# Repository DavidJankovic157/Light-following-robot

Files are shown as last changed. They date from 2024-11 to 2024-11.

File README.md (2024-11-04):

A robot that moves away from light using the dsPIC30F4013 microcontroller and suitable sensors. The PCB for this project is designed with Altium Designer 17. Details on the sensors and code operation are provided in the documentation.

Upotrebom dsPIC30F4013 mikrokontrolera i odgovarajućih senzora realizovan je robot koji se kreće suprotno od izvora svetlosti. PCB za ovaj projekat realizovan je pomoću Altium Designer-a 17. Detaljne informacije o senzorima i principu rada koda nalaze se u pratećoj dokumentaciji.

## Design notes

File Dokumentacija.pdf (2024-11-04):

# PROJEKAT IZ PRIMENJENE ELEKTRONIKE

NAZIV PROJEKTA:

Autonomni robot za detekciju svetlosti i izbegavanje prepreka

MENTOR PROJEKTA:

Prof. dr Vladimir Rajs

Msc Milan Bodić

Msc Marko Vasiljević Toskić

PROJEKAT IZRADILI:

Anđela Smiljanić ee133/2019

Luka Urošević ee154/2019

David Janković ee157/2019

DATUM ODBRANE PROJEKTA:

## Sadržaj

## 1. Uvod

Kada smo bili deca igrali smo se sa raznim igračkama koje su se kretale po unapred zadatim putanjama, bez obzira na prepreke koje predstoje. Ovaj projekat podseća na te trenutke, ali sada umesto praćene fiksne rute, reaguje na promene u okruženju, prilagođava svoje kretanje prema svetlosti i izbegava prepreke.

Cilj ovog projekta je razviti algoritam koji omogućava robotu da se kreće u pravcu suprotnom od izvora svetlosti, koristeći fotootpornike za detekciju njenog intenziteta. Postavljanje četiri fotootpornika omogućava robotu da „oseća“ svetlost iz različitih pravaca i automatski prilagođava svoj pravac kretanja – povlači se iz osvetljenih zona i traži tamnija područja.

Robot takođe koristi Bluetooth komunikaciju za primanje jednostavnih komandi "START" i "STOP", pružajući korisniku mogućnost da započne ili prekine njegovo kretanje u bilo kom trenutku. Bluetooth modul nije samo sredstvo kontrole, već i veza koja robotu daje mogućnost interakcije sa spoljnim svetom, otvarajući vrata za dalji razvoj sistema koji mogu reagovati na složenije signale.

Da bi osigurao sigurno kretanje, robot je opremljen sa dva HC-SR04 senzora za izbegavanje prepreka, čime postaje sposoban da se autonomno kreće bez rizika od sudara. Ovi senzori skeniraju okolinu ispred i iza robota, omogućavajući mu da izbegne prepreke i sačuva stabilnost u svakoj fazi kretanja.

Na taj način, ovaj projekat predstavlja savršenu kombinaciju jednostavnih tehnologija, poput fotootpornika i senzora daljine, sa osnovnim elementima robotike i komunikacije. Rezultat je robot koji uči da reaguje na svetlo i prepreke, pružajući korisniku jedinstven uvid u svet interaktivnih i autonomnih sistema.

## 2. Opis elemenata projekta

2.1.Bluetooth HC- 06

HC-06 Bluetooth modul je jednostavan i pouzdan uređaj koji omogućava bežičnu komunikaciju sa pametnim telefonima, računarima ili drugim Bluetooth uređajima. Konfigurisan je kao slave uređaj, što znači da uvek čeka da se poveže sa uređajem koji je konfigurisani kao master, kao što su telefoni ili računari. Modul podržava Bluetooth verziju 2.0 i omogućava prenos podataka pri brzinama do 2.1 Mbps, što ga čini pogodnim za mnoge projekte koji zahtevaju pouzdanu bežičnu vezu.

HC-06 koristi radni napon od 3.3V i ima radnu struju manju od 40mA, što ga čini efikasnim u potrošnji energije. Komunikacija sa ovim modulom ostvaruje se putem UART interfejsa, što omogućava jednostavno povezivanje sa mikrokontrolerima i drugim uređajima koji podržavaju serijski port. Modul dolazi sa integrisanom antenom koja omogućava stabilan prenos podataka na udaljenosti do 10 metara, što je dovoljno za mnoge aplikacije gde se traži bežična kontrola ili prenos podataka.

Povezivanje HC-06 sa mikrokontrolerom je prilično jednostavno. Modul ima četiri pina – VCC, GND, TX i RX. VCC pin se povezuje
na napajanje od 3.3V, GND na uzemljenje,
dok se TX i RX koriste za slanje i primanje
podataka.

Kada se uključi, HC-06 postaje dostupan za uparivanje, a pametni telefon ili računar mogu ga pronaći putem Bluetooth
pretrage. Nakon što je uparen, uređaj može
slati i primati podatke preko serijskog

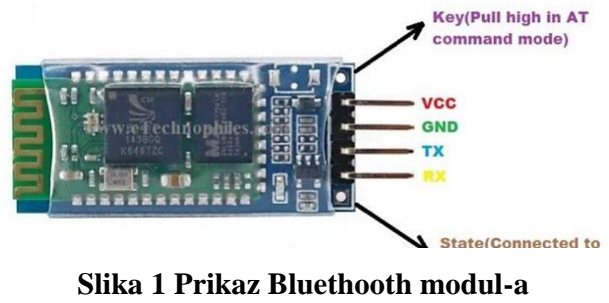
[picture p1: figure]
Slika 1 Prikaz Bluethooth modul-a

interfejsa. To omogućava jednostavnu implementaciju bežične kontrole robota, prikupljanje podataka sa senzora ili daljinsko upravljanje različitim uređajima.

HC-06 je široko korišćen u projektima koji zahtevaju bežičnu komunikaciju, posebno u robotici, Internet of Things (IoT) uređajima i aplikacijama gde je potrebna jednostavna bežična interakcija sa mikrokontrolerom. [1]

2.2.Ultrazvučni senzor HC-SR04

Ovaj projekat koristi HC-SR04 ultrazvučni senzor kako bi robot mogao da detektuje prepreke i meri udaljenost od objekata u svom okruženju. Cilj je da robot autonomno izbegava prepreke, koristeći podatke o udaljenosti u realnom vremenu, što omogućava glatko i bezbedno kretanje. Senzor funkcioniše tako što emituje ultrazvučni signal koji se odbija od objekata, a zatim meri vreme potrebno da se taj signal vrati. Na osnovu izmerenog vremena, izračunava se udaljenost do objekta. HC-SR04 može meriti udaljenost u rasponu od 2 cm do 4 metra, pružajući precizne i pouzdane informacije.

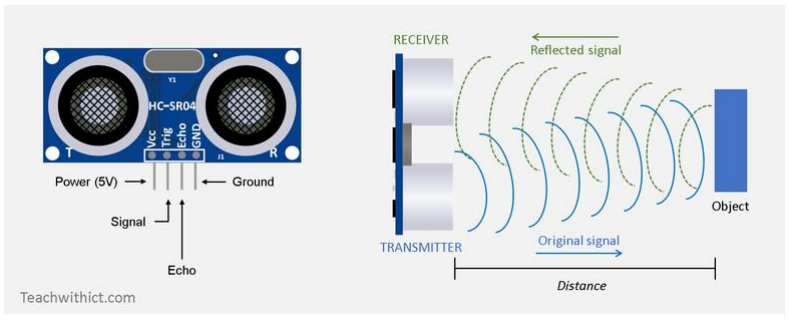
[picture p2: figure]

Komunikacija sa senzorom je jednostavna i ostvaruje se putem četiri pina – VCC, GND, Trigger i Echo. VCC pin se povezuje na napajanje od 3.3V ili 5V, dok se GND povezuje na uzemljenje. Trigger pin je zadužen za slanje impulsa mikrokontrolera, a Echo pin vraća signal koji predstavlja dužinu trajanja eha. Na osnovu ovog povratnog signala mikrokontroler izračunava vreme koje je bilo potrebno da se ultrazvučni talas odbije od prepreke i vrati, a zatim na osnovu toga računa udaljenost do objekta koristeći formulu:

D =

V ∗ T
2
Gde je D rastojanje, V brzina zvuka (340 m/s), a T proteklo vreme od emitovanja do povratka talasa. Proizvod brzine zvuka i proteklog vremena deli se sa dva jer talasi putuju od modula do prepreke i nazad.

Brzina zvuka je ključna za precizno merenje udaljenosti. Na primer, na temperaturi od 20℃ u suvom vazduhu, brzina zvuka je oko 340 m/s. Ovo daje dovoljno vremena da senzor pošalje impuls i primi povratni signal. Međutim, brzina prostiranja zvuka može značajno varirati u različitim sredinama – u tečnostima može biti preko 1000 m/s, a u čvrstim materijalima i nekoliko hiljada metara u sekundi. S obzirom na ove faktore, HC-SR04 je pouzdano rešenje za detekciju prepreka u vazduhu, omogućavajući robotima da izbegnu sudare u realnom vremenu.

Zahvaljujući jednostavnosti korišćenja, ovaj senzor je pogodan za različite aplikacije, od robotike i detekcije prepreka, do naprednijih sistema za merenje i navigaciju. [2]

Slika 2.2a Ultrazvučni senzor

2.3.Fotootpornik

Ovaj otpornik je izrađen od poluprovodnog materijala. Kada fotoni svetlosti padaju na fotootpornik sa dovoljno visokom frekvencijom (odnosno dovoljnom energijom), oni pružaju vezanim elektronima dovoljnu energiju da postanu slobodni elektroni u poluprovodniku. Ovaj proces rezultuje smanjenjem otpora fotootpornika pod uticajem svetlosti.

Fotootpornici imaju prednosti u vidu niske cene i pouzdanosti, ali imaju i svoje nedostatke, među kojima je spor odziv. Naime, obično je potrebno nekoliko sekundi za potpunu promenu otpora fotootpornika prilikom naglog promenjenog osvetljenja. Ovo često može biti ograničavajuće u situacijama gde je brza reakcija na promene u osvetljenju od suštinskog značaja. [3]

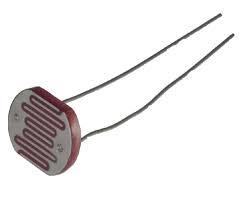
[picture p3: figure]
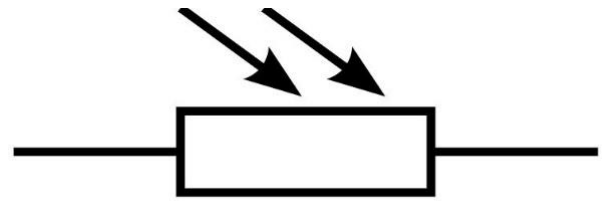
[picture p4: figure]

Slika 2a izgled fotootpornika(levo) i šematski prikaz(desno)

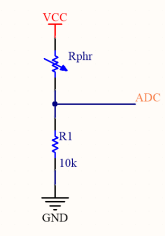
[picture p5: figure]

Slika 2b Izgled šematika za povezivanje fotootporinika sa mikrokontrolerom

2.4.Programator
PICkit je serija programatora za PIC mikrokontrolere koju proizvodi Microchip Technology. Ovi uređaji se koriste za programiranje mikrokontrolera, otklanjanje grešaka i programiranje EEPROM memorija. U našem projektu koristili smo PICkit 2, koji se izdvaja po tome što ima odvojenu jedinicu za programiranje i debagovanje koja se povezuje sa pločom na kojoj se nalazi čip koji treba programirati.

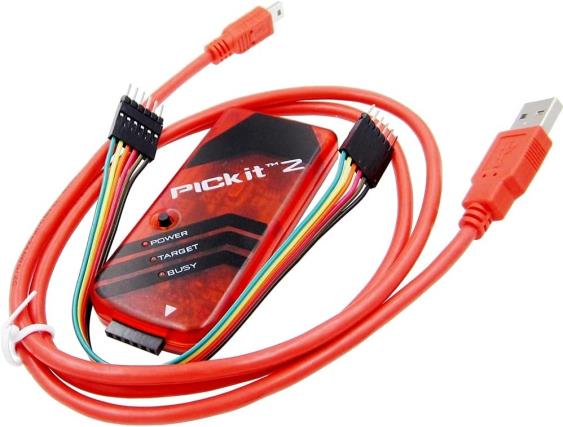
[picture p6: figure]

PICkit 2 dolazi sa 128 KB memorije kao standardnom opremom, dok je moguće proširiti kapacitet na 256 KB modifikovanjem hardvera ili korišćenjem klonova trećih strana. Ovaj programator takođe uključuje ugrađeni trokanalni logički analizator od 500 kHz i UART alat, što dodatno olakšava analizu i debagovanje sistema.

Sistem PICkit 2 sadrži pet ključnih pinova za programiranje mikrokontrolera: VDD (napajanje), VSS (masa), PGD (Program Data), PGC (Program Clock) i MCLR (RESET), uz dodatni šesti slobodni pin. Pinovi PGC i PGD su povezani sa RB6 i RB7 pinovima mikrokontrolera, omogućavajući efikasnu komunikaciju i programiranje. [4]

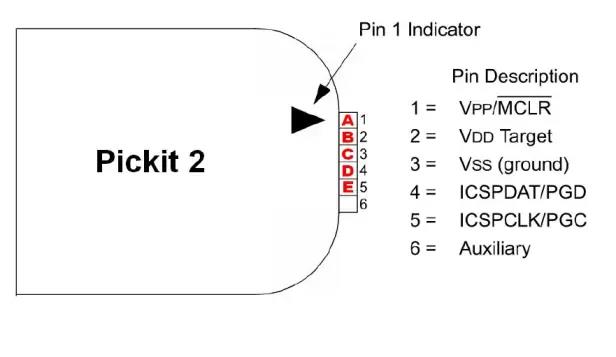
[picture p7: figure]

Slika 2.4b Pickit 2 pinovi

Slika 2.4a Pickit 2

## 3. HARDVERSKA STRUKTURA

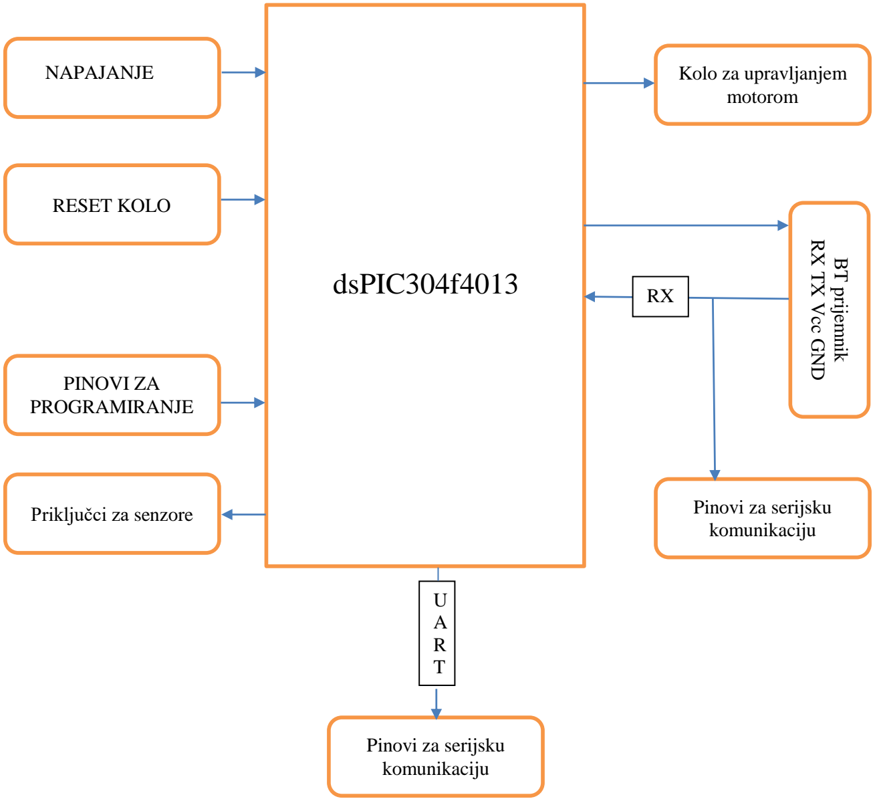
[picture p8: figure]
RESET KOLO; Priključci za senzore; PINOVI ZA PROGRAMIRANJE; Kolo za upravljanjem motorom; BT prijemnik; RX TX Vcc GND; Pinovi za serijsku komunikaciju; dsPIC304f4013; NAPAJANJE

## 4. ŠEMATIK

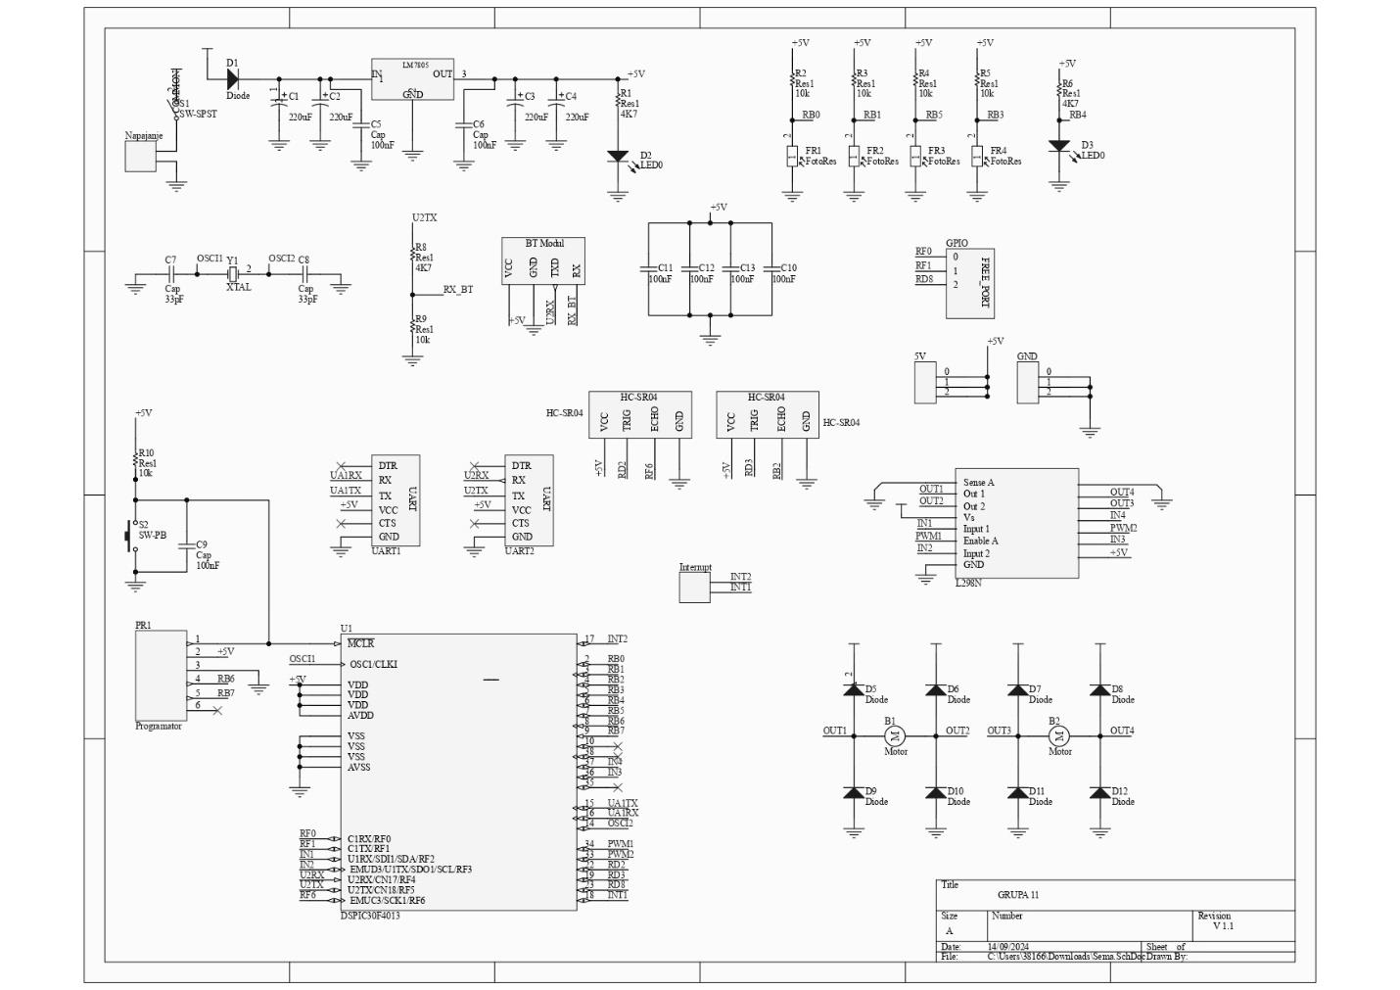
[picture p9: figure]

Slika 4.1a Izgled šematika u Altium Designer-u

## 5. OPIS PODSISTEMA ŠEMATIKA

### 5.1. Blok za napajanje

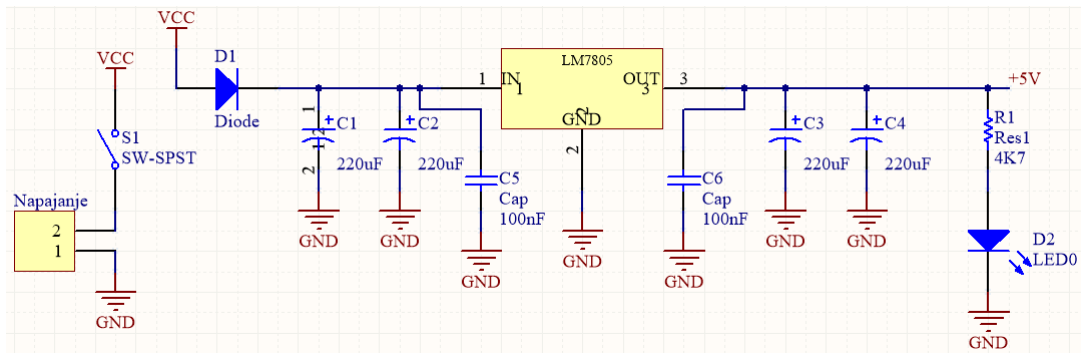
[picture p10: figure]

Slika 5.1a Šematski prikaz bloka za napajanje

Glavni deo ovog segmenta čini stabilizator napona LM7805.

On predstavlja jedan od najčešćih naponskih regulatora korišćen za ograničavanje napona. Na izlazu naponskog regulatora dobija se vrednost od 5V sa 2% maksimalne devijacije.

Kako bi se ostvario stabilan izlaz, neophodno je napajati kolo sa minimum 7V. Za potrebe projekta je upotrebljeno napajanje od 9V. Na izlazu kola nalazi se LED koja služi za indikaciju da li je kolo u funkciji. [5]

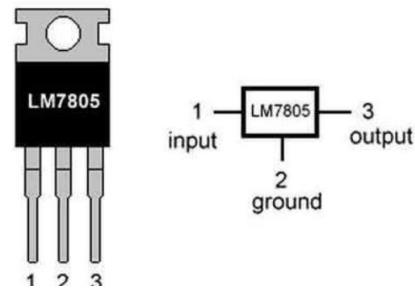
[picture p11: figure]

Slika 5.1b Izgled kućišta LM7805 sa rasporedom pinova

### 5.2. Mikrokontroler dsPIC30f4013

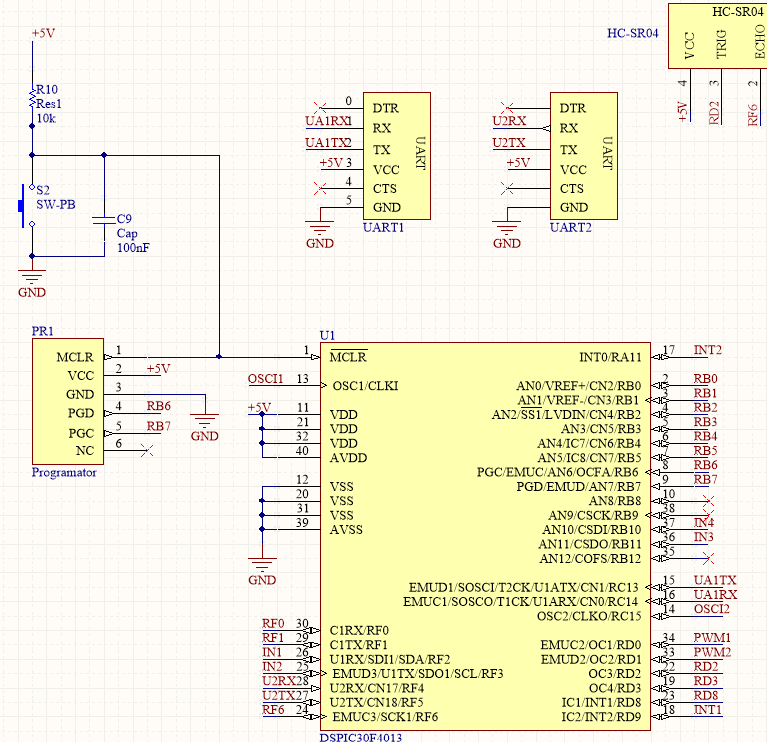
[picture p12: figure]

Slika 5.2a Šematski prikaz mikrokontrolera dsPIC30f4013

Mikrokontroleri su postali neophodni element svakog elektronskog uređaja, igrajući ključnu ulogu u prikupljanju podataka, ograničene obrade tih podataka i upravljanju okruženjem na osnovu rezultata izračunavanja. U okviru ovog projekta, izabran je mikrokontroler dsPIC30f4013 proizvođača Microchip. Ovaj mikrokontroler ima radni napon radni napon u rasponu od 2.5V do 5.5V. Poseduje pet vrsta portova (A,B,C,D,E,F), pet tajmera, dva UART modula sa FIFO baferima i 12-bitni Analogno-Digitalni (A/D) konvertor sa 13 ulaznih kanala. Njegove karakteristike uključuju nisku potrošnju energije i visoku brzinu rada. [6]

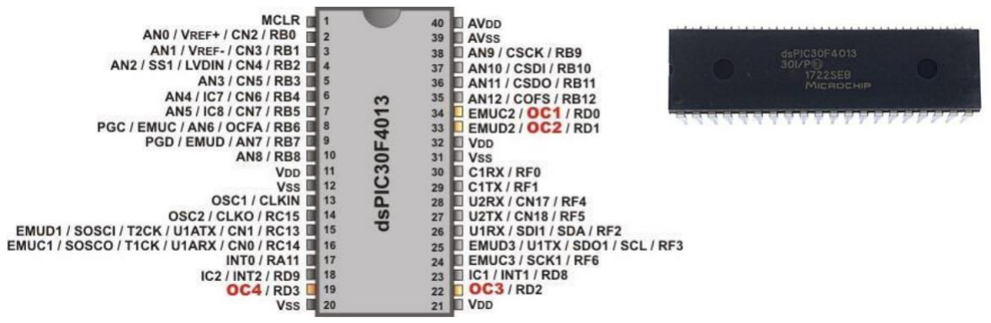
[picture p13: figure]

Slika 5.2b Raspored priključaka Mikrokontrolera dsPIC30f4013(levo) i izgled mikrokontrolera(desno)

U zadatku smo koristili eksterni oscilator čiji je instrukcioni takt iznosi 10MHz.

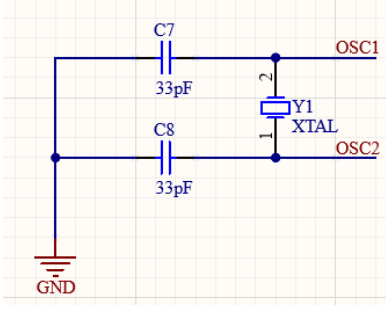
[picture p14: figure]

Slika 5.2c Prikaz oscilatora

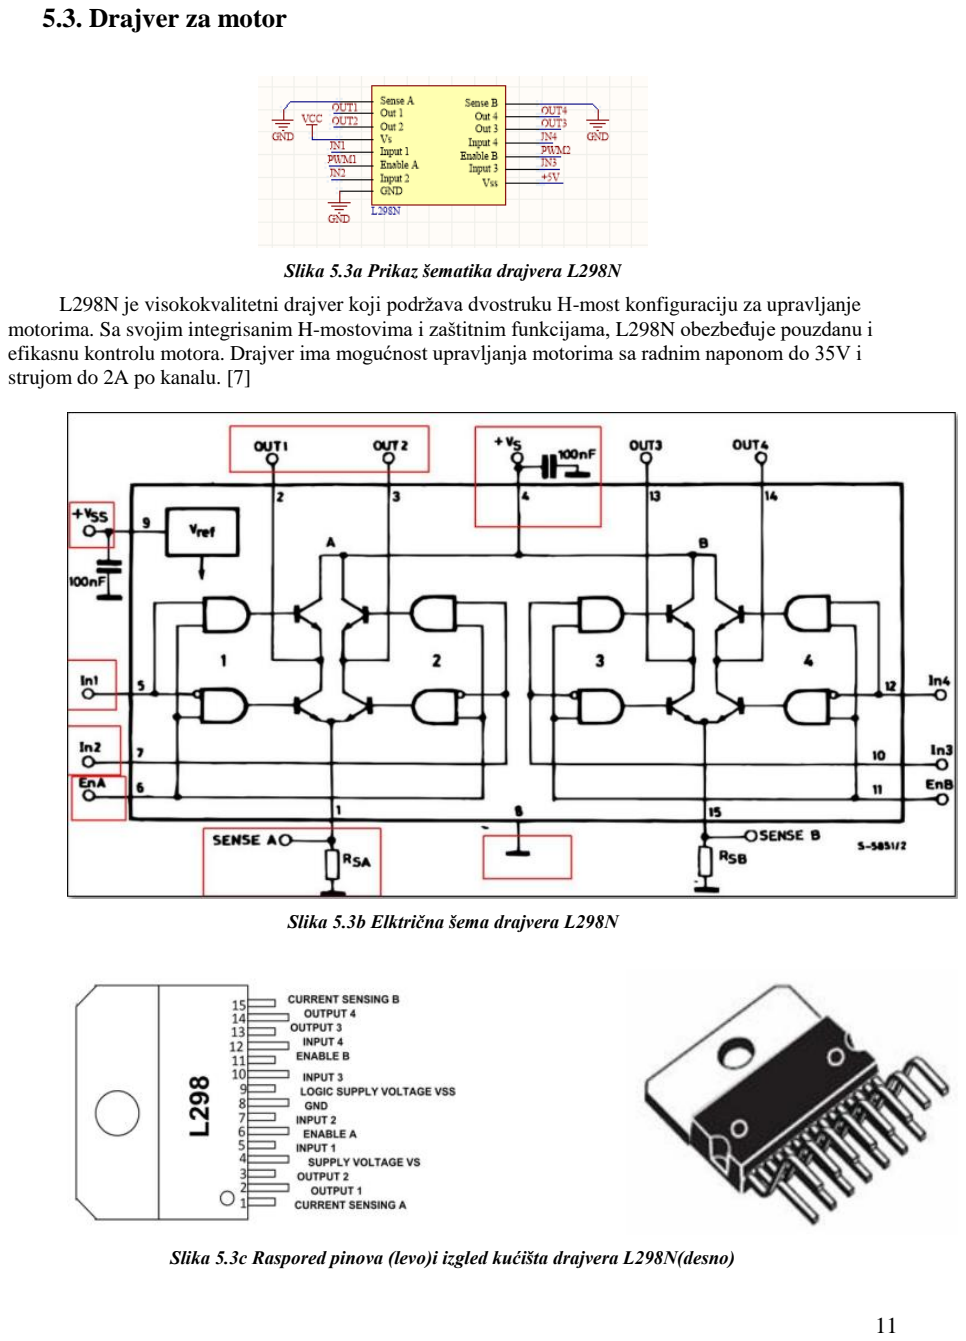
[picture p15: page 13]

### 5.3. Drajver za motor

Slika 5.3a Prikaz šematika drajvera L298N L298N je visokokvalitetni drajver koji podržava dvostruku H-most konfiguraciju za upravljanje motorima. Sa svojim integrisanim H-mostovima i zaštitnim funkcijama, L298N obezbeđuje pouzdanu i efikasnu kontrolu motora. Drajver ima mogućnost upravljanja motorima sa radnim naponom do 35V i strujom do 2A po kanalu. [7]

Slika 5.3b Elktrična šema drajvera L298N

Slika 5.3c Raspored pinova (levo)i izgled kućišta drajvera L298N(desno)

### 5.4. Reset kolo

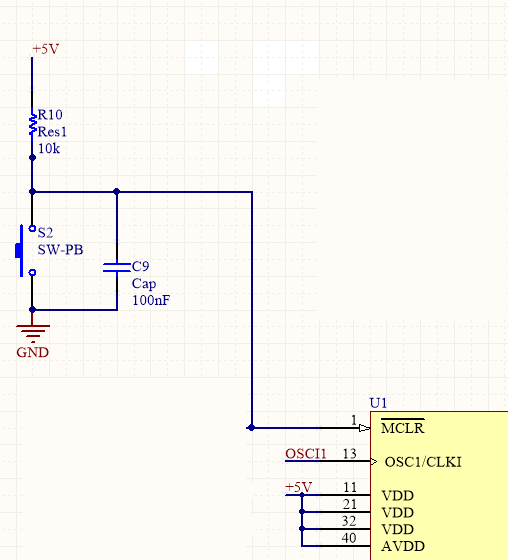
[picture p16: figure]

Slika 5.4a Šematik reset kola

Reset kolo služi da se resetuje mikrokontroler. Realizovano je u vidu pull-up tastera, kod koga se taster nalazi paralelno kondenzatoru (100pF), jedan kraj ide na masu, drugi na otpornik koji se povezuje na napajanje (5V). Kondenzator služi kao hardversko rešenje poskakivanju tastera (eng. debouncing). Izlaz reset kola je izmedju otpornika i paralelne veze tastera i kondenzatora. Pritiskom na taster dobijamo nizak logički nivo, što signalizira sistemu da izvrši reset i odgovara samom MCLR ̅̅̅̅̅̅̅̅̅̅̅̅̅̅̅̅̅̅̅̅̅̅̅̅̅̅̅̅̅̅̅̅̅̅̅̅̅̅̅̅̅̅̅̅̅̅̅̅̅̅̅̅̅̅̅̅̅̅̅̅̅̅̅̅
na koji se vezuje izlaz
našeg reset kola. Kada se taster otpusti prekida se putanja ka masi i imamo visok logički nivo i vraćamo se u stanje mirovanja, neakativno stanje reset kola.

## 6. Prikaz PCB

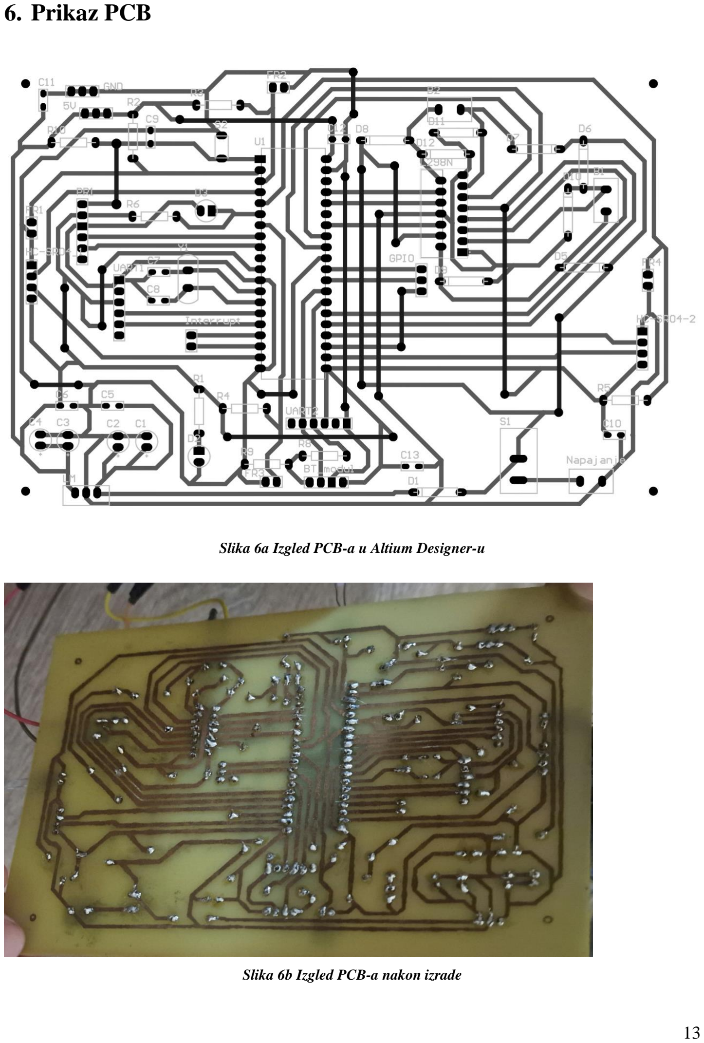
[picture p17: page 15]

Slika 6a Izgled PCB-a u Altium Designer-u

Slika 6b Izgled PCB-a nakon izrade

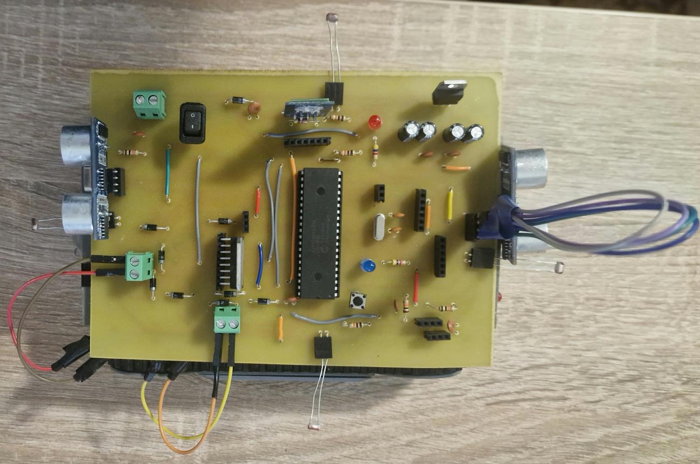
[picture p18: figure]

Slika 6c Izgled povezanog autića spreman za test

## 7. Izrada pločice

Koraci prilikom izrade štampane pločice:

- Priprema vitroplasta: Šmirglanje i čišćenje pločice.
- Prebacivanje dizajna: Prenos dizajna na pločicu peglanjem.
- Utapanje u kiselinu: Nagrizanje bakra na nepokrivenim delovima dizajna.
- Bušenje rupa: Izrada rupa za komponente.
- Postavljanje komponenata: Instalacija svih elektronskih delova.
- Testiranje: Provera funkcionalnosti pločice.

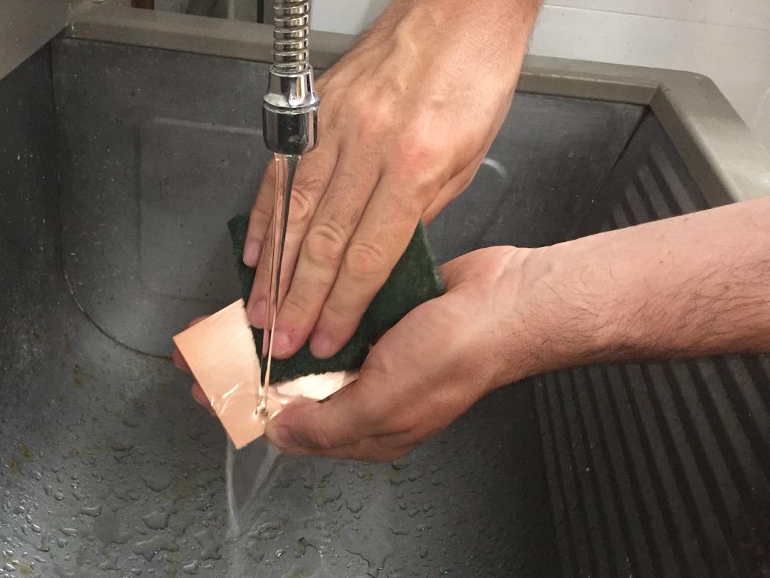
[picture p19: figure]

Slika 7a Način izrade PCB-a

## 8. Algoritam rada

8.1Prikaz algoritma

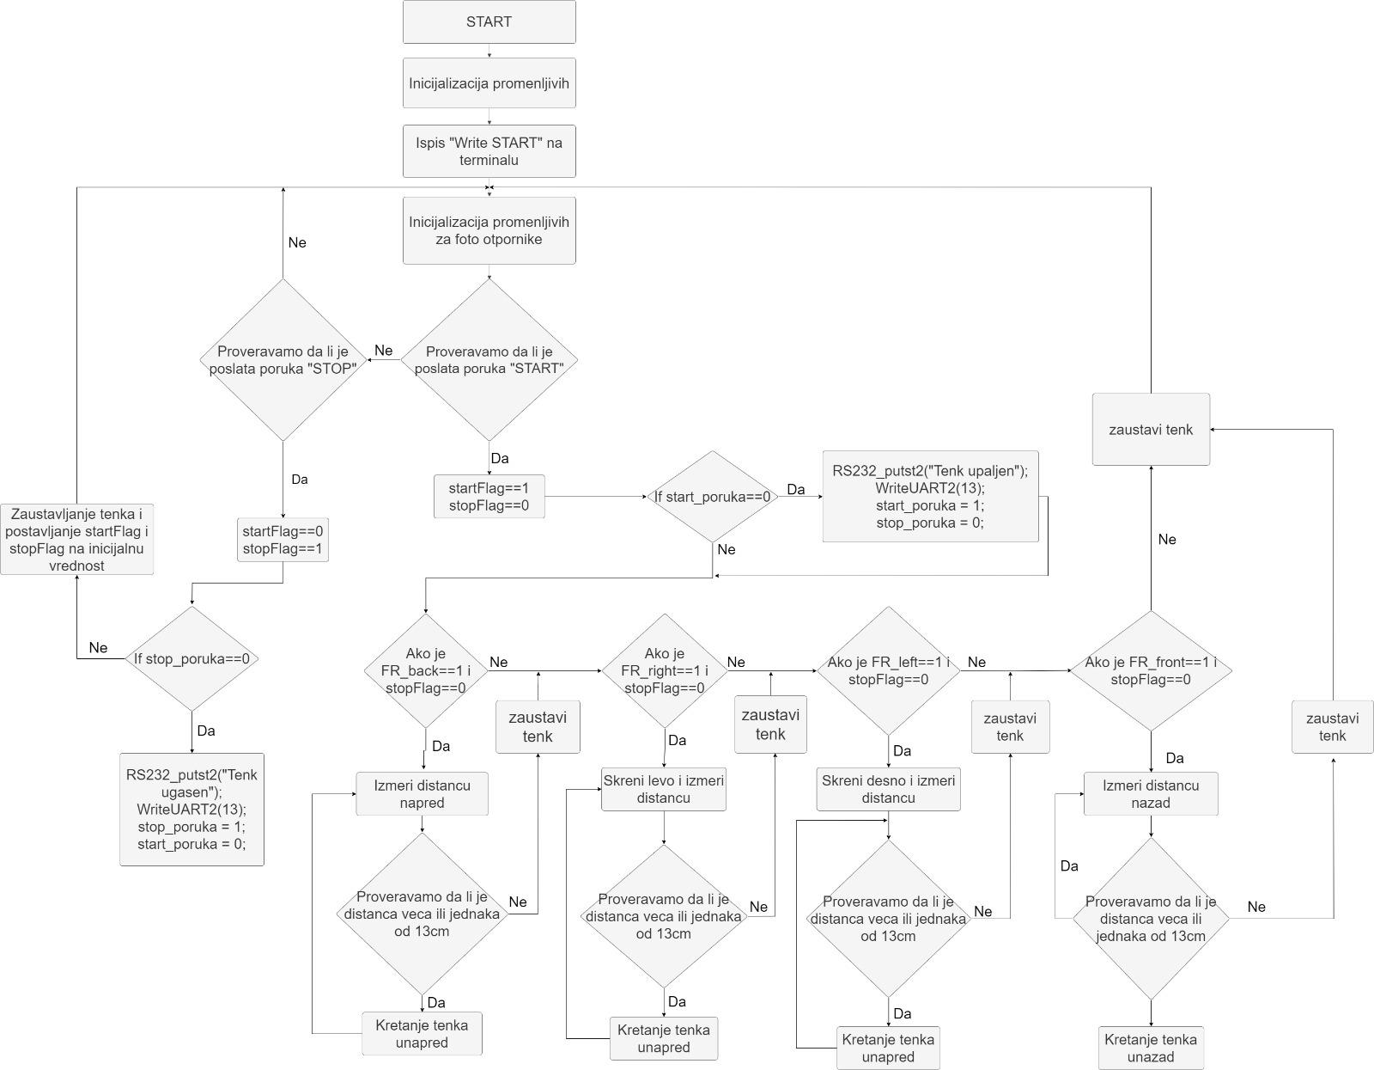
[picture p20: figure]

Slika 8a Izgled algoritma rada

8.2Realizacija main-a

#include <stdio.h>

#include <stdlib.h>

#include <p30fxxxx.h>

#include <outcompare.h>

#include <string.h>

#include "adc.h"

#include "tajmer.h"

#include "tajmer_pwm.h"

#include "UART.h"

#include "fotootpornik.h"

#include <stdint.h>

#define BUFFER_SIZE 6

//#define TRIG_NAPRED LATDbits.LATD2 //#define ECHO_NAPRED PORTFbits.RF6

//#define TRIG_NAZAD LATDbits.LATD3 //#define ECHO_NAZAD PORTBbits.RB2

#define TRIG_NAPRED LATDbits.LATD3 #define ECHO_NAPRED PORTBbits.RB2

#define TRIG_NAZAD LATDbits.LATD2 #define ECHO_NAZAD PORTFbits.RF6

#define SPEED_OF_SOUND (0.0343) | // centimetri po mikcrosec.

#define INSTRUCTION_CLOCK_PERIOD (0.1) // microsekundi

_FOSC(CSW_FSCM_OFF &XT_PLL4); // instruction takt je isti kao i kristal 10MHz _FWDT(WDT_OFF);

unsigned char tempRX1, tempRX2_bluetooth;
unsigned int us_counter;
unsigned int sirovi0, sirovi1, sirovi2, sirovi3; unsigned int FR_front, FR_back, FR_left, FR_right; int startFlag = 0;
int stopFlag = 0;

char buffer[BUFFER_SIZE];
unsigned int bufferIndex = 0;

static unsigned char time_overflow_back = 0; static unsigned char time_overflow_forward = 0; static float measured_distance_back = 0;
static float measured_distance_forward = 0;

void __attribute__((__interrupt__, no_auto_psv)) _T1Interrupt(void) // svakih 1us
{
TMR1 = 0;

us_counter++; // brojac za funkciju delay_1us()

IFS0bits.T1IF = 0;
}

void __attribute__((__interrupt__, no_auto_psv)) _T2Interrupt(void) // za PMW

{
TMR2 = 0;
IFS0bits.T2IF = 0;
}

void __attribute__((__interrupt__, no_auto_psv)) _T4Interrupt(void)//za dig senzor nazad
{
TMR4 = 0;
ECHO_NAZAD = 0;
time_overflow_back = 1;
IFS1bits.T4IF = 0;
}

void __attribute__((__interrupt__, no_auto_psv)) _T5Interrupt(void) // za dig senzor napred
{
TMR5 = 0;
ECHO_NAPRED = 0;
time_overflow_forward = 1; IFS1bits.T5IF = 0;
}

void __attribute__((__interrupt__, no_auto_psv)) _U2RXInterrupt(void) { IFS1bits.U2RXIF = 0;

tempRX2_bluetooth = U2RXREG;

//proveri da li je primljeni karakter prelaz u novi red //Provera da li je primljen karakter novi red
if (tempRX2_bluetooth == '\n' || tempRX2_bluetooth == '\r') { // Null- prekida ga
buffer[bufferIndex] = '\0';

// Slanje poruke "START"
if (strcmp(buffer, "START") == 0) { //startFlag postavljamo na 1 startFlag = 1;

}// Slanje poruke "STOP"
else if (strcmp(buffer, "STOP") == 0) { //stopFlag postavljamo na 1
stopFlag = 1;
}
//Resetujemo bufferIndex za sledeci prijem bufferIndex = 0;
}//Proveravamo da li je buffer pun
else if (bufferIndex < BUFFER_SIZE - 1) { //Dodajemo primljen karakter u bafer buffer[bufferIndex] = tempRX2_bluetooth; bufferIndex++;
}
}

void __attribute__((__interrupt__, no_auto_psv)) _U1RXInterrupt(void) { IFS0bits.U1RXIF = 0;
tempRX1 = U1RXREG;
}

void __attribute__((__interrupt__, no_auto_psv)) _ADCInterrupt(void) {

sirovi0 = ADCBUF0;
sirovi1 = ADCBUF1;
sirovi2 = ADCBUF2;
sirovi3 = ADCBUF3;

IFS0bits.ADIF = 0;
}

void initPins() {

// FOTOOTPORNICI analogni
ADPCFGbits.PCFG0 = 0; // levi-fotoR na RB0 ADPCFGbits.PCFG1 = 0; // gornji-fotoR na RB1 ADPCFGbits.PCFG5 = 0; // donji-fotoR na RB5 ADPCFGbits.PCFG3 = 0; // desni-fotoR na RB3

TRISBbits.TRISB0 = 1; // ulazni TRISBbits.TRISB1 = 1; // ulazni TRISBbits.TRISB5 = 1; // ulazni TRISBbits.TRISB3 = 1; // ulazni

// ULTRAZVUCNI NAPRED
TRISDbits.TRISD2 = 0; // trigger TRISFbits.TRISF6 = 1; // echo

// ULTRAZVUCNI NAZAD
TRISDbits.TRISD3 = 0; // trigger

ADPCFGbits.PCFG2 = 1; // digitalni pin TRISBbits.TRISB2 = 1; // echo

// pinovi za kretanje
TRISFbits.TRISF2 = 0; // in1 TRISFbits.TRISF3 = 0; // in2

ADPCFGbits.PCFG10 = 1;
TRISBbits.TRISB10 = 0; // in4

ADPCFGbits.PCFG11 = 1;
TRISBbits.TRISB11 = 0; // in3

// pwm
TRISDbits.TRISD1 = 0; // enB TRISDbits.TRISD0 = 0; // enA }

void delay_1us(int vreme) { us_counter = 0;
T1CONbits.TON = 1;
while (us_counter < vreme) ;
T1CONbits.TON = 0;
}

void delay_for(uint32_t num) // unsigned int ide do 65535 {
uint32_t broj;
for (broj = 0; broj < num; broj++)
;
}

static void MeasureBackDistance() {
//logicka jedinica traje 10us
TRIG_NAZAD = 1;
delay_1us(3); //3 od 10 da bi nam logicka jedinica trajala 10us TRIG_NAZAD = 0;
delay_1us(3);
while (!ECHO_NAZAD)
; //echo pin postaje 1(rastuca ivica detektovana) TMR4 = 0; // resetuje se tajmer T4
IFS1bits.T4IF = 0;
T4CONbits.TON = 1; // ukljucujemo tajmer T4
while (ECHO_NAZAD)
; //echo pin postaje 0(opadajuca ivica detektovana) T4CONbits.TON = 0; //isljucujemo tajmer T4
unsigned int measured_time_back;
if (time_overflow_back == 1) //
{
measured_time_back = TMR4_period; time_overflow_back = 0;
} else //poslati signal se vratio
{
measured_time_back = TMR4;
}
TMR4 = 0;
// delimo sa 2 jer svetlosni signal putuje do prepreke i nazad
// mnozimo sa INSTRUCTION_CLOCK_PERIOD da bi dobili vreme u mikrosekundama
measured_distance_back = (measured_time_back * INSTRUCTION_CLOCK_PERIOD) / 2 * SPEED_OF_SOUND;
}

static void MeasureForwardDistance() {

TRIG_NAPRED = 1;
delay_1us(3);
TRIG_NAPRED = 0;
delay_1us(3);
while (!ECHO_NAPRED)
;
TMR5 = 0;
IFS1bits.T5IF = 0;
T5CONbits.TON = 1;
while (ECHO_NAPRED)
;
T5CONbits.TON = 0;
unsigned int measured_time_forward;
if (time_overflow_forward == 1)
{
measured_time_forward = TMR5_period; time_overflow_forward = 0;
} else
{
measured_time_forward = TMR5;
}
TMR5 = 0;
measured_distance_forward = (measured_time_forward * INSTRUCTION_CLOCK_PERIOD) / 2 * SPEED_OF_SOUND;
}

void idiNapred() {

// | OC1RS=250;
// | OC2RS=250;

LATFbits.LATF2 = 0; // in1 LATFbits.LATF3 = 1; // in2 LATBbits.LATB11 = 1; // in3 LATBbits.LATB10 = 0; // in4 }

void idiNazad() {

// OC1RS=385;
// OC2RS=400;

LATFbits.LATF2 = 1; // in1 LATFbits.LATF3 = 0; // in2 LATBbits.LATB11 = 0; // in3 LATBbits.LATB10 = 1; // in4 }

void idiLevo() {

// | OC1RS=250;
// | OC2RS=250;

LATFbits.LATF2 = 1; // in1 LATFbits.LATF3 = 0; // in2 LATBbits.LATB11 = 1; // in3 LATBbits.LATB10 = 0; // in4 }

void idiDesno() {

// OC1RS=250;
// OC2RS=250;

LATFbits.LATF2 = 0; // in1 LATFbits.LATF3 = 1; // in2 LATBbits.LATB11 = 0; // in3 LATBbits.LATB10 = 1; // in4 }

void zaustaviSve() {

// OC1RS = 0;
// OC2RS = 0;

LATFbits.LATF2 = 0; // in1 LATFbits.LATF3 = 0; // in2 LATBbits.LATB11 = 0; // in3 LATBbits.LATB10 = 0; // in4 }
int start_poruka = 0;
int stop_poruka = 0;

int main(int argc, char **argv) { initPins();
ADCinit();
initUART2(); // bluetooth
initUART1(); // za serijsku i debugging Init_T1();

Init_T4();
Init_T5();
initPWM();

RS232_putst2("Write START"); WriteUART2(13);

while (1) {

FR_back = fotootpornik(sirovi0); // promenjive za svaki fotootpornik pokazuju da li je on osvjetljen FR_right = fotootpornik(sirovi1);
FR_front = fotootpornik(sirovi2);
FR_left = fotootpornik(sirovi3);

if (startFlag == 1 && stopFlag == 0) {

if (start_poruka == 0) {
RS232_putst2("Tenk upaljen"); WriteUART2(13);
start_poruka = 1;
stop_poruka = 0;
}

if (FR_back == 1 && stopFlag == 0) {

MeasureBackDistance(); // Izmeri udaljenost unazad
if (measured_distance_back > 13) {
idiNazad(); // Ako je udaljenost unazad veca od 13, kreni nazad while (measured_distance_back >= 13 && stopFlag == 0) { MeasureBackDistance(); // Ponovo izmeri udaljenost unazad if (measured_distance_back < 13) {
zaustaviSve(); // Zaustavi tenk ako je udaljenost unazad manja od 13 }
}
} else {
zaustaviSve(); // Zaustavite tenk ako je udaljenost unazad vec manja od 13 }
} else if (FR_right == 1 && stopFlag == 0) {

idiDesno();
delay_for(705000); // delay realizovan ovako da se tenk okrene za 90 stepeni MeasureForwardDistance(); // Izmeri udaljenost unapred
if (measured_distance_forward >= 13) {
idiNapred(); // Ako je udaljenost unapred veca od 13, kreni napred while (measured_distance_forward >= 13 && stopFlag == 0) {
MeasureForwardDistance(); // Ponovo izmeri udaljenost unapred if (measured_distance_forward < 13) { zaustaviSve(); // Zaustavi tenk ako je udaljenost unapred manja od 13 }
}
} else {
zaustaviSve(); // Zaustavi tenk ako je udaljenost unapred vec manja od 13 }
} else if (FR_front == 1 && stopFlag == 0) {

MeasureForwardDistance(); // Izmeri udaljenost unapred
if (measured_distance_forward > 13) {
idiNapred(); // Ako je udaljenost unapred veca od 13,kreni napred while (measured_distance_forward >= 13 && stopFlag == 0) {
MeasureForwardDistance(); // Ponovo izmeri udaljenost unapred if (measured_distance_forward < 13) { zaustaviSve(); // Zaustavi tenk ako je udaljenost unapred manja od 13 }
}
} else {
zaustaviSve(); //Zaustavi tenk ako je udaljenost unapred vec manja od 13 }
} else if (FR_left == 1 && stopFlag == 0) {

idiLevo();
delay_for(705000); //delay realizovan ovako da se tenk okrene za 90 stepeni MeasureForwardDistance();
if (measured_distance_forward >= 13) {
idiNapred(); // Ako je udaljenost unapred veca od 13, kreni napred while (measured_distance_forward >= 13 && stopFlag == 0) {
MeasureForwardDistance(); // Ponovo izmeri udaljenost unapred if (measured_distance_forward < 13) { zaustaviSve(); // Zaustavi tenk ako je udaljenost unapred manja od 13 }
}
} else {
zaustaviSve(); // Zaustavi tenk ako je udaljenost unapred vec manja od 13 }
} else {
zaustaviSve(); // Zaustavi tenk ako nijedan fotootpornik nije osvetljen }
} else if (stopFlag == 1) {

if (stop_poruka == 0) {
RS232_putst2("Tenk ugasen"); WriteUART2(13);
stop_poruka = 1;
start_poruka = 0;
}
zaustaviSve();
stopFlag = 0;
startFlag = 0;
}

} // od while

return 0;
}

## 9.ZAKLJUČAK

Nakon završetka projekta, utvrdili smo da uređaj uspešno izvršava sve zadate funkcije koristeći potrebne komponente. Ipak, uočeni su i neki izazovi. Fotootpornici imaju ograničen domet detekcije, dok HC-SR04 senzori mogu biti osetljivi na ambijentalnu buku ili prepreke koje deformišu ultrazvučne talase, što može uzrokovati netačna merenja udaljenosti. Takođe, mogu biti podložni interferencijama kada se koriste u blizini drugih uređaja koji emituju ultrazvuk.

Poboljšanja bi mogla uključivati dodavanje dodatnih senzora, poput infracrvenih za precizniju detekciju prepreka, kao i implementaciju navigacionih algoritama koji bi omogućili složenije odluke pri kretanju robota, poput pronalaženja optimalnih puteva ili mapiranja okoline. Integracija kamere bi omogućila vizuelno prepoznavanje okoline, dok bi dodavanje više funkcija putem Bluetooth-a proširilo mogućnosti uređaja.

Tokom ovog projekta, naš tim je stekao značajno iskustvo u projektovanju, programiranju i testiranju robotskih sistema, kao i u radu sa senzorima i Bluetooth komunikacijom. Pored tehničkih veština, projekat je omogućio razvijanje sposobnosti rešavanja problema i timskog rada.

## 10.LITERATURA

[1] U. electronics, „HC-06 bluetooth modu,“ [Na mreži]. Available: https://www.utmel.com/components/hc-06-bluetooth-module-pinout-datasheet-pdf-and-arduino-connection?id=884. [Poslednji pristup 14. 09. 2024].
[2] „OSEPP Electronics LTD HC-SR04,“ [Na mreži]. Available: https://www.utmel.com/productdetail/oseppelectronicsltd-hcsr04-8415088. [Poslednji pristup 14. 09. 2024].
[3] „Data sheet za fotootpornik“ [Na mreži]. Available: https://eepower.com/resistor-guide/resistor-types/photo-resistor/. [Poslednji pristup 14. 09. 2024].
[4] „PICkit 2 Programmer/Debugger User's Guide,“ 14 09 2024. [Na mreži]. Available: https://ww1.microchip.com/downloads/aemDocuments/documents/OTH/ProductDocuments/UserGuides/51553E.pdf.
[5] „Data sheet za Lm7805,“ [Na mreži]. Available: https://www.alldatasheet.com/datasheetpdf/pdf/82833/FAIRCHILD/LM7805.html. [Poslednji pristup 19. 09. 2024].
[6] „Data Sheet mikrokontrolera dsPIC30f4013,“ [Na mreži]. Available: https://ww1.microchip.com/downloads/en/devicedoc/70138c.pdf. [Poslednji pristup 19. 09. 2024].
[7] „Data Sheet za L298N,“ [Na mreži]. Available: https://www.alldatasheet.com/datasheetpdf/pdf/22440/STMICROELECTRONICS/L298N.html;. [Poslednji pristup 19. 9. 2024].
[8] Rajs V. Praktikum za vežbe iz Primenjene elektronike. Novi Sad: Fakultet tehničkih nauka, 2020.
[9] M. Živanov, Uvod u elektroniku, Novi Sad: FTN, 2013.
[10] Materijal u vidu prezentacija iz predmeta Primenjena elektronika za školsku 2023/2024

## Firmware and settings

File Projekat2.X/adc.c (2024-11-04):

#include<p30fxxxx.h>

#include "adc.h"



void ADCinit(void)
{


/*
ADCON1:

bit 15 ADON: A/D Operating Mode bit
	1 = A/D converter module is operating
	0 = A/D converter is off
bit 14 Unimplemented: Read as ?0?
bit 13 ADSIDL: Stop in Idle Mode bit
	1 = Discontinue module operation when device enters Idle mode
	0 = Continue module operation in Idle mode
bit 12-10 Unimplemented: Read as ?0?
bit 9-8 FORM<1:0>: Data Output Format bits
	11 = Signed fractional (DOUT = sddd dddd dddd 0000)
	10 = Fractional (DOUT = dddd dddd dddd 0000)
	01 = Signed integer (DOUT = ssss sddd dddd dddd)
	00 = Integer (DOUT = 0000 dddd dddd dddd)
bit 7-5 SSRC<2:0>: Conversion Trigger Source Select bits
	111 = Internal counter ends sampling and starts conversion (auto convert)
	110 = Reserved
	101 = Reserved
	100 = Reserved
	011 = Motor Control PWM interval ends sampling and starts conversion
	010 = General purpose Timer3 compare ends sampling and starts conversion
	001 = Active transition on INT0 pin ends sampling and starts conversion
	000 = Clearing SAMP bit ends sampling and starts conversion
bit 4-3 Unimplemented: Read as ?0?
bit 2 ASAM: A/D Sample Auto-Start bit
	1 = Sampling begins immediately after last conversion completes. SAMP bit is auto set.
	0 = Sampling begins when SAMP bit set
bit 1 SAMP: A/D Sample Enable bit
	1 = At least one A/D sample/hold amplifier is sampling
	0 = A/D sample/hold amplifiers are holding
	When ASAM = 0, writing ?1? to this bit will start sampling.
	When SSRC = 000, writing ?0? to this bit will end sampling and start conversion.
bit 0 DONE: A/D Conversion Status bit
	1 = A/D conversion is done
	0 = A/D conversion is not done
	Clearing this bit will not effect any operation in progress.
	Cleared by software or start of a new conversion.*/


ADCON1bits.ADSIDL=0;
ADCON1bits.FORM=0;
ADCON1bits.SSRC=7;
//na kraju  ADCON1bits.ASAM=1;
ADCON1bits.SAMP=1;
//ADCON1bits.ADON=1;      //ovo na kraju



/*
ADCON2:

bit 15-13 VCFG<2:0>: Voltage Reference Configuration bits

			A/D	VREFH	 			A/D VREFL
	000 	AVDD 					AVSS
	001 	External VREF+ pin 		AVSS
	010 	AVDD 					External VREF- pin
	011 	External VREF+ pin 		External VREF- pin
	1xx 	AVDD 					AVSS

bit 12 Reserved: User should write ?0? to this location

bit 11 Unimplemented: Read as ?0?

bit 10 CSCNA: Scan Input Selections for CH0+ S/H Input for MUX A Input Multiplexer Setting bit
	1 = Scan inputs
	0 = Do not scan inputs

bit 9-8 Unimplemented: Read as ?0?

bit 7 BUFS: Buffer Fill Status bit
	Only valid when BUFM = 1 (ADRES split into 2 x 8-word buffers)
	1 = A/D is currently filling buffer 0x8-0xF, user should access data in 0x0-0x7
	0 = A/D is currently filling buffer 0x0-0x7, user should access data in 0x8-0xF

bit 6 Unimplemented: Read as ?0?

bit 5-2 SMPI<3:0>: Sample/Convert Sequences Per Interrupt Selection bits
	1111 = Interrupts at the completion of conversion for each 16th sample/convert sequence
	1110 = Interrupts at the completion of conversion for each 15th sample/convert sequence
	.....
	0001 = Interrupts at the completion of conversion for each 2nd sample/convert sequence
	0000 = Interrupts at the completion of conversion for each sample/convert sequence

bit 1 BUFM: Buffer Mode Select bit
	1 = Buffer configured as two 8-word buffers ADCBUF(15...8), ADCBUF(7...0)
	0 = Buffer configured as one 16-word buffer ADCBUF(15...0)

bit 0 ALTS: Alternate Input Sample Mode Select bit
	1 = Uses MUX A input multiplexer settings for first sample, then alternate between MUX B and MUX A input
	multiplexer settings for all subsequent samples
	0 = Always use MUX A input multiplexer settings*/

ADCON2bits.VCFG=7;
ADCON2bits.CSCNA=1;
ADCON2bits.SMPI=3; //4 raw values - 1
ADCON2bits.BUFM=0;
ADCON2bits.ALTS=0;


/*
ADCON3:

bit 15-13 Unimplemented: Read as ?0?
bit 12-8 SAMC<4:0>: Auto Sample Time bits
	11111 = 31 TAD
	?????
	00001 = 1 TAD
	00000 = 0 TAD
bit 7 ADRC: A/D Conversion Clock Source bit
	1 = A/D internal RC clock
	0 = Clock derived from system clock
bit 6 Unimplemented: Read as ?0?
bit 5-0 ADCS<5:0>: A/D Conversion Clock Select bits
	111111 = TCY/2 ? (ADCS<5:0> + 1) = 32 ? TCY
	??????
	000001 = TCY/2 ? (ADCS<5:0> + 1) = TCY
	000000 = TCY/2 ? (ADCS<5:0> + 1) = TCY/2*/

ADCON3bits.SAMC=31;
ADCON3bits.ADRC=1;
ADCON3bits.ADCS=31;

/*
ADCHS: A/D Input Select Register

bit 15-13 Unimplemented: Read as ?0?
bit 12 CH0NB: Channel 0 Negative Input Select for MUX B Multiplexer Setting bit
	Same definition as bit <4> (see Note).
bit 11-8 CH0SB<3:0>: Channel 0 Positive Input Select for MUX B Multiplexer Setting bit
	Same definition as bits <3:0> (see Note).
bit 7-5 Unimplemented: Read as ?0?
bit 4 CH0NA: Channel 0 Negative Input Select for MUX A Multiplexer Setting bit
	1 = Channel 0 negative input is AN1
	0 = Channel 0 negative input is VREFbit
3-0 CH0SA<3:0>: Channel 0 Positive Input Select for MUX A Multiplexer Setting bit
	1111 = Channel 0 positive input is AN15
	1110 = Channel 0 positive input is AN14
	1101 = Channel 0 positive input is AN13
	?????
	0001 = Channel 0 positive input is AN1
	0000 = Channel 0 positive input is AN0
*/
ADCHSbits.CH0NB=0;
ADCHSbits.CH0NA=0;

ADCHSbits.CH0SA=0;
ADCHSbits.CH0SB=0;

/*ADPCFG: A/D Port Configuration Register

bit 15-0 PCFG<15:0>: Analog Input Pin Configuration Control bits
	1 = Analog input pin in Digital mode, port read input enabled, A/D input multiplexer input connected to AVSS
	0 = Analog input pin in Analog mode, port read input disabled, A/D samples pin voltage*/

//ADPCFG=0; 


/*ADCSSL: A/D Input Scan Select Register

bit 15-0 CSSL<15:0>: A/D Input Pin Scan Selection bits
	1 = Select ANx for input scan
	0 = Skip ANx for input scan*/
//ADCSSL=0b0001111111111111;
  ADCSSL=0b0000000000101011;  //fotoR na RB0 levi,RB1 gornji,RB5 donji,RB3 desni
ADCON1bits.ASAM=1;

IFS0bits.ADIF=1;
IEC0bits.ADIE=1;


    ADCON1bits.ADON = 1; //Pocetak AD konverzije

}
